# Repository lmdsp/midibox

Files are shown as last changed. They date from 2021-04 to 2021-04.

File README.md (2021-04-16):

# Midibox PCBs

A collection of schematics and printed circuit board layouts for various [Midibox NG](http://www.ucapps.de/midibox_ng.html) modules,
made with [KiCAD](https://kicad.org/).
The designs were made with MCU style MIDI control surfaces in mind, but could also be useful for other applications.

- [Midibox PCBs](#midibox-pcbs)
  - [OLED carrier board](#oled-carrier-board)
    - [Bill of materials](#bill-of-materials)
    - [Assembly](#assembly)
    - [Connections](#connections)
      - [Internal power](#internal-power)
      - [External power](#external-power)
      - [PCB top side / OLED pin headers](#pcb-top-side--oled-pin-headers)
      - [PCB bottom side / other components](#pcb-bottom-side--other-components)
  - [TODO](#todo)

## OLED carrier board

Holds eight 0.96″ OLED screens, spaced by 1.2″ for a compact design.

Only 4-wire SPI, 7-pin OLED types are supported.
Be sure to check the dimensions and pinout matches before purchase!

Optional decoupling 100nF caps `C1`-`C8` can be stuffed to improve noise rejection in case of flickering or other issues.

### Bill of materials

- OLED screen x 8
- 10k 1/4W resistor
- 10µF/35V radial capacitor
- 2x8 box connector socket
- 2x8 box headers x 2
- 16-way cable
- 7-pin sockets x 8 (0.1″ spacing, for the OLEDs)
- 3-pin header
- 2-pin jumper
- 100nF ceramic capacitor x 8 (optional)

### Assembly

1. Solder the sockets for the OLEDs on the top side
2. Solder all other components on the bottom side
3. Connect `J2` to `core/J15A` using a ribbon cable
4. Configure the software

### Connections

`J1` connects to `J15A` of the [STM32F4 core](http://www.ucapps.de/mbhp_core_stm32f4.html).

#### Internal power

`J15_S` should be set to 3.3V on the core, and `JP1` to _Core_ on this PCB.

#### External power

The LDO regulator on the core board can only supply 100mA.
Therefore this PCB has an option to use external 3.3V power through `J2`.
In this case `JP1` should be set to _Ext_.

#### PCB top side / OLED pin headers

----
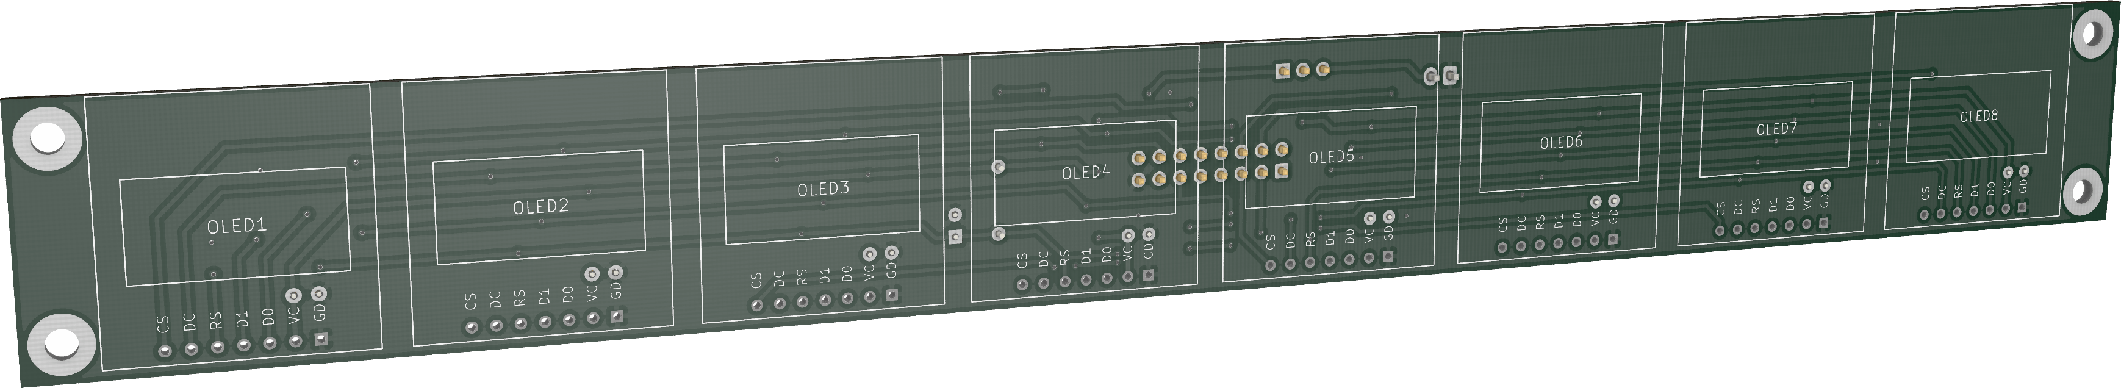
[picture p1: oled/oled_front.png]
OLED front


----

#### PCB bottom side / other components

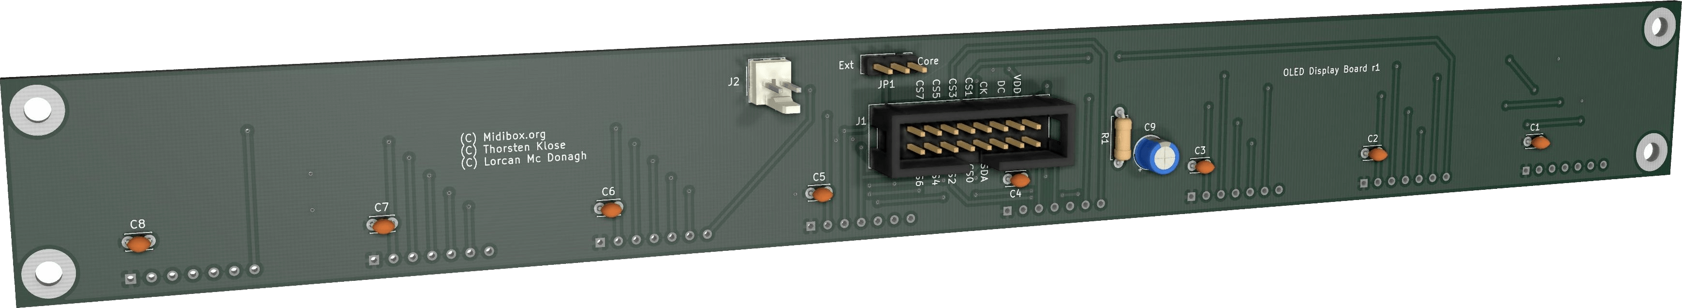
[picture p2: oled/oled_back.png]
OLED back


----

## TODO

- Software configuration
- Secure OLED mechanically
- Photos of PCB and working displays

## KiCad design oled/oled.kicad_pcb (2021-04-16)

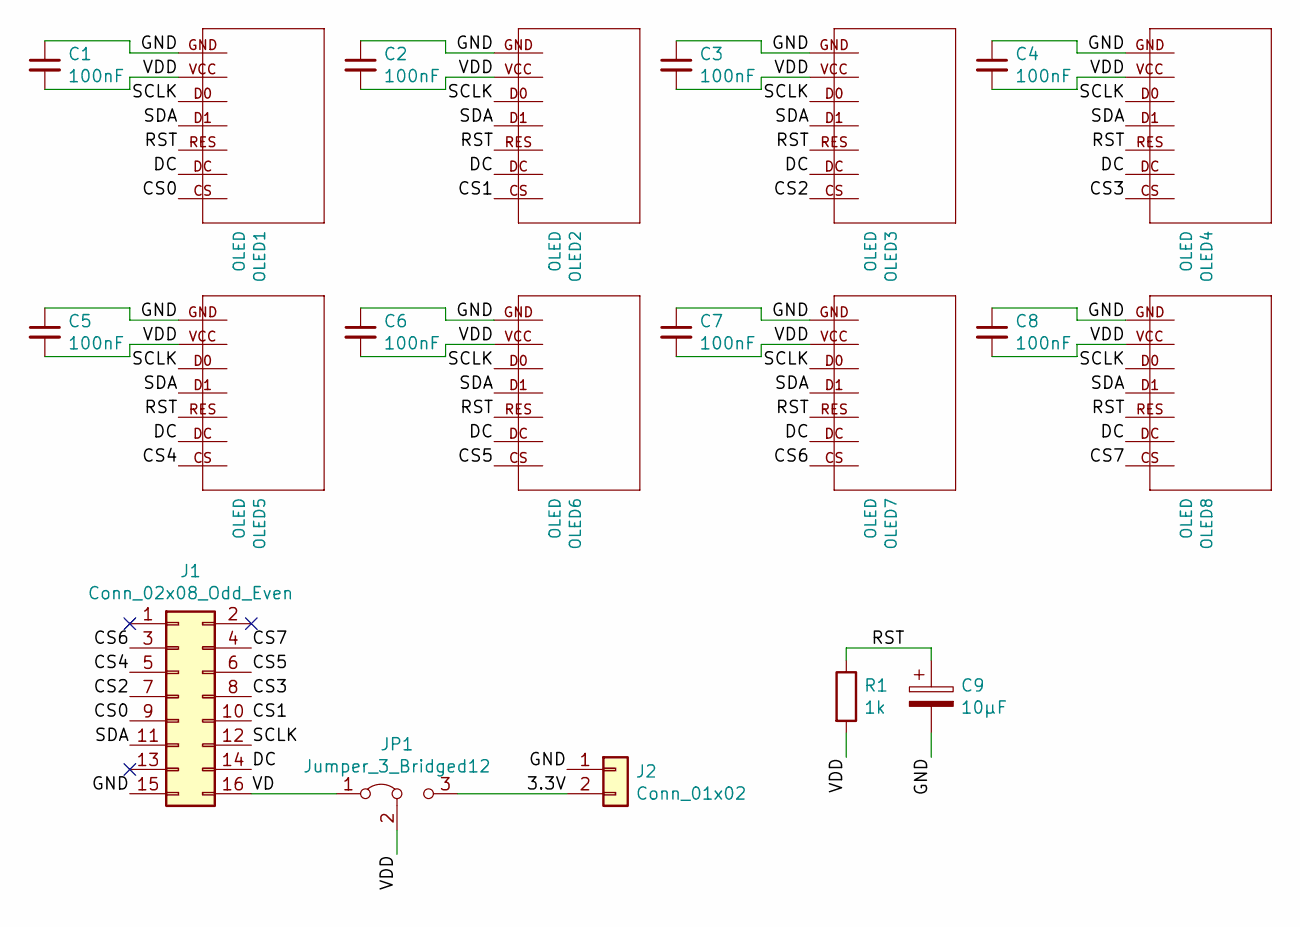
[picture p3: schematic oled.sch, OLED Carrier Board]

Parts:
C1, C2, C3, C4, C5, C6, C7, C8: 100nF; C_Disc_D3.0mm_W2.0mm_P2.50mm
C9: 10µF; CP_Radial_D5.0mm_P2.50mm
J1: Conn_02x08_Odd_Even; IDC-Header_2x08_P2.54mm_Vertical
J2: Conn_01x02; Molex_KK-254_AE-6410-02A_1x02_P2.54mm_Vertical
JP1: Jumper_3_Bridged12; PinHeader_1x03_P2.54mm_Vertical
OLED1, OLED2, OLED3, OLED4, OLED5, OLED6, OLED7, OLED8: OLED; oled-128x64-4spi-0.96
R1: 1k; R_Axial_DIN0207_L6.3mm_D2.5mm_P7.62mm_Horizontal

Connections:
/3.3V: J2.2, JP1.3 (B)
/CS0: J1.9, OLED1.CS
/CS1: J1.10, OLED2.CS
/CS2: J1.7, OLED3.CS
/CS3: J1.8, OLED4.CS
/CS4: J1.5, OLED5.CS
/CS5: J1.6, OLED6.CS
/CS6: J1.3, OLED7.CS
/CS7: J1.4, OLED8.CS
/DC: J1.14, OLED1.DC, OLED2.DC, OLED3.DC, OLED4.DC, OLED5.DC, OLED6.DC, OLED7.DC, OLED8.DC
/GND: C1.1, C2.1, C3.1, C4.1, C5.1, C6.1, C7.1, C8.1, C9.2, J1.15, J2.1, OLED1.GND, OLED2.GND, OLED3.GND, OLED4.GND, OLED5.GND, OLED6.GND, OLED7.GND, OLED8.GND
/RST: C9.1, OLED1.RES, OLED2.RES, OLED3.RES, OLED4.RES, OLED5.RES, OLED6.RES, OLED7.RES, OLED8.RES, R1.1
/SCLK: J1.12, OLED1.D0, OLED2.D0, OLED3.D0, OLED4.D0, OLED5.D0, OLED6.D0, OLED7.D0, OLED8.D0
/SDA: J1.11, OLED1.D1, OLED2.D1, OLED3.D1, OLED4.D1, OLED5.D1, OLED6.D1, OLED7.D1, OLED8.D1
/VD: J1.16, JP1.1 (A)
/VDD: C1.2, C2.2, C3.2, C4.2, C5.2, C6.2, C7.2, C8.2, JP1.2 (C), OLED1.VCC, OLED2.VCC, OLED3.VCC, OLED4.VCC, OLED5.VCC, OLED6.VCC, OLED7.VCC, OLED8.VCC, R1.2

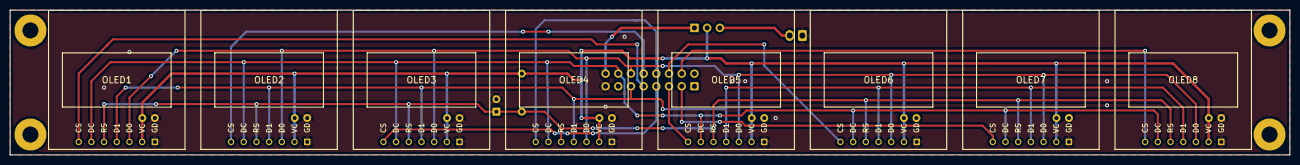
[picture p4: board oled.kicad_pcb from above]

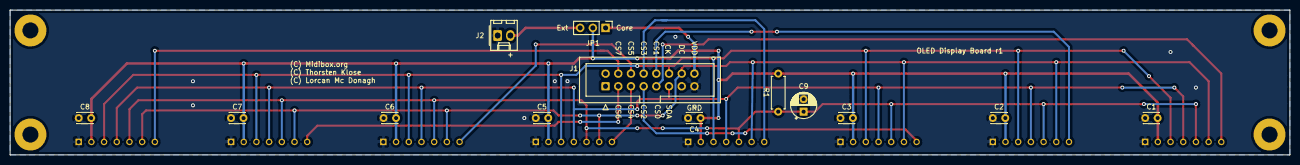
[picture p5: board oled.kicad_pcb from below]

Board: 2 copper layers, 256.0 x 29.0 mm, 21 parts (13 on the bottom side), 16 nets.
